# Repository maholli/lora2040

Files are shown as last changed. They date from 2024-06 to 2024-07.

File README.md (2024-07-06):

# lora2040

Just playing with RP2040 w/ mram + SX1262 radio.

Will eventually reduce the size and add castellations for "mezzanine" style surface mounting.



# Example Software - Meshtastic RX
1. Open serial terminal ([can use chrome or edge with this link](https://googlechromelabs.github.io/serial-terminal/) if you don't already have a preferred serial terminal method)
   
2. Ctrl+e for paste-mode
3. Paste the following:
   ```python
   import time
   from machine import Pin, SPI
   # Uses the official micropython-lib lora sx1262 lib
   # https://github.com/micropython/micropython-lib/tree/master/micropython/lora
   from lora import SX1262
   
   # meshtastic default "LongFast" on default frequency slot 20
   lora_cfg = {
       "freq_khz": 906_875,
       "sf": 11,
       "bw": "250",  # kHz
       "coding_rate": 5,
       "preamble_len": 16,
       "output_power": 0,  # dBm
       # "syncword":0x2B, # SETTING SYNCWORD MUST BE DONE MANUALLY. SEE BELOW
       "rx_boost":True,
   }
      
   print("Initializing...")
   
   modem = SX1262(
       spi=SPI(0, baudrate=8_000_000, polarity=0, phase=0,
               sck=Pin(18), miso=Pin(16), mosi=Pin(19)),
       cs=Pin(17),
       reset=Pin(20),
       busy=Pin(21),
       dio1=Pin(25),
       dio2_rf_sw=True,
       dio3_tcxo_millivolts=2800,
       lora_cfg=lora_cfg,
   )
   
   # set custom meshtastic syncword
   modem._cmd(">BHH", 0x0D, 0x740, 0x24b4) # 0x2B == 0x24b4
   
   print("Listening...")
   
   print("[Packet payload, Timestamp (ms), SNR (dB*4), RSSI (dBm), Valid CRC]")
   while True:
       modem.recv()
   ```
4. Ctrl+d to run
5. Any packets received will be printed (note meshtastic payloads will still be encrypted):
   

-----

Reminders to myself:
- [x] Initial bring-up with Everspin MRAM
  - [ ] Avalanche MRAM
- [x] Full speed SX1262 interface
- [ ] Measure TX output power
- [ ] Measure RX sensitivity
- [ ] Maybe add an amp at some point?

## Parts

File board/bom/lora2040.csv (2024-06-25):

Reference | Value | Footprint | Qty | Part Number | Manufacturer | Description
C1 | 47nF | custom-footprints:sx126x_C_0201 | 1 |  |  | Multilayer ceramic capacitors X5R ±10%, 16V
C2 | 47pF | custom-footprints:sx126x_C_0201 | 1 |  |  | Multilayer ceramic capacitors COG ±5%, 50V
C3,C4 | 15pF | custom-footprints:sx126x_C_0201 | 2
C5,C6,C10,C11,C12,C13,C18,C21,C23 | 0.1uF | custom-footprints:sx126x_C_0201 | 9 |  |  | -- mixed values --
C7,C9,C24,C26 | 1uF | Capacitor_SMD:C_0402_1005Metric | 4
C8 | 39pF | custom-footprints:sx126x_C_0201 | 1 |  |  | Multilayer ceramic capacitors COG ±5%, 50V
C14,C15 | 1nF | custom-footprints:sx126x_C_0201 | 2 |  |  | Unpolarized capacitor, small symbol
C16 | 1uF | custom-footprints:sx126x_C_0402 | 1 |  |  | Unpolarized capacitor, small symbol
C17 | 470nF | custom-footprints:sx126x_C_0402 | 1 |  |  | Unpolarized capacitor, small symbol
C19,C20 | 0.1uF | Capacitor_SMD:C_0402_1005Metric | 2
C22 | 10pF | custom-footprints:sx126x_C_0201 | 1 |  |  | Unpolarized capacitor, small symbol
C25 | 10nF | Capacitor_SMD:C_0402_1005Metric | 1
C27 | 10uF | Capacitor_SMD:C_0402_1005Metric | 1
D1 | LED | LED_SMD:LED_0402_1005Metric | 1 |  |  | Light emitting diode
FB1 | BLM15PG100SN1D | custom-footprints:sx126x_L_0402 | 1 | BLM15PG100SN1D | Murata Electronics | Ferrite bead, small symbol
J1 | u.FL | Connector_Coaxial:U.FL_Hirose_U.FL-R-SMT-1_Vertical | 1 |  |  | coaxial connector (BNC, SMA, SMB, SMC, Cinch/RCA, LEMO, ...)
J2 | USB_B_Micro | Connector_USB:USB_Micro-B_Molex-105017-0001 | 1 |  |  | USB Micro Type B connector
J5 | Conn_01x02 | Connector_PinHeader_1.00mm:PinHeader_1x02_P1.00mm_Vertical | 1 |  |  | Generic connector, single row, 01x02, script generated (kicad-library-utils/schlib/autogen/connector/)
J6 | Conn_02x06_Odd_Even | Connector_PinHeader_1.00mm:PinHeader_2x06_P1.00mm_Vertical | 1 |  |  | Generic connector, double row, 02x06, odd/even pin numbering scheme (row 1 odd numbers, row 2 even numbers), script generated (kicad-library-utils/schlib/autogen/connector/)
J8 | Conn_01x04 | Connector_PinHeader_1.00mm:PinHeader_1x04_P1.00mm_Vertical | 1 |  |  | Generic connector, single row, 01x04, script generated (kicad-library-utils/schlib/autogen/connector/)
L1 | 47nH | custom-footprints:sx126x_L_0402 | 1 | LQW15AN47NJ00D | Murata Electronics | FIXED IND 47NH 210MA 1.08OHM SMD
L7 | 15uH | custom-footprints:sx126x_L_0805 | 1 | MLZ2012M150WT000 | TDK Corporation | FIXED IND 15UH 250MA 950MOHM SMD
R1,R9 | 10K | custom-footprints:sx126x_R_0201 | 2
R2 | 1K | Resistor_SMD:R_0402_1005Metric | 1
R3,R4 | 100 | custom-footprints:sx126x_R_0201 | 2
R6,R7 | 27 | custom-footprints:sx126x_R_0201 | 2
R8,R11 | 1K | custom-footprints:sx126x_R_0201 | 2
R10 | 220 | custom-footprints:sx126x_R_0201 | 1
U1 | SX1262IMLTRT | custom-footprints:VQFN24_4X4MM_SX126x | 1 | SX1262IMLTRT | Semtech Corporation | 150 MHz to 960 MHz Low Power Long Range Transceiver, 22dBm output power, spreading factor from 5 to 12, LoRA, QFN-24
U2 | BGS12WN6E6327 | Package_LGA:Infineon_PG-TSNP-6-10_0.7x1.1mm_0.7x1.1mm_P0.4mm | 1 | BGS12WN6E6327 | Infineon Technologies | SPDT DC-9GHz switch, 45dB isolation at 960MHz, PG-TSNP-6-10
U3 | 0900FM15K0039001E | custom-footprints:0900FM15K0039 | 1 | 0900FM15K0039001E | Johanson Technology Inc. | 868MHz/915MHz Sub-GHz Impedance Matched Filter integrated passive for Semtech SX1261, SX1262, LLCC68
U4 | MR20H40 or AS3004204 | custom-footprints:SON127P600X500X90-9N | 1 | AS3004204-0054X0PWAY | Avalanche Technology | 4Mb MRAM memory with SPI interface, DFN-8
U5 | RP2040 | Package_DFN_QFN:QFN-56-1EP_7x7mm_P0.4mm_EP3.2x3.2mm | 1 | SC0914 | Raspberry Pi | IC MCU 32BIT EXT MEM 56QFN
U6 | RTX-2016BD32-S-32.000-TR | custom-footprints:TXCO_2.0x1.6 | 1 | RTX-2016BD32-S-32.000-TR | Raltron Electronics | Raltron Electronics XTAL OSC TCXO 32MHZ 2.8V CLP SNW
U7 | TPS73633DBV or MIC5219-3.3YM5-TR? | Package_TO_SOT_SMD:SOT-23-5 | 1 | MIC5219-3.3YM5-TR | Microchip Technology | Cap free NMOS 400mA Low Drop 3.3V Regulator, SOT-23-5
Y2 | ABM8-272-T3 | Crystal:Crystal_SMD_3225-4Pin_3.2x2.5mm | 1 | ABM8-272-T3 | Abracon LLC | CRYSTAL 12.0000MHZ 10PF SMD GND ON 2 AND 4

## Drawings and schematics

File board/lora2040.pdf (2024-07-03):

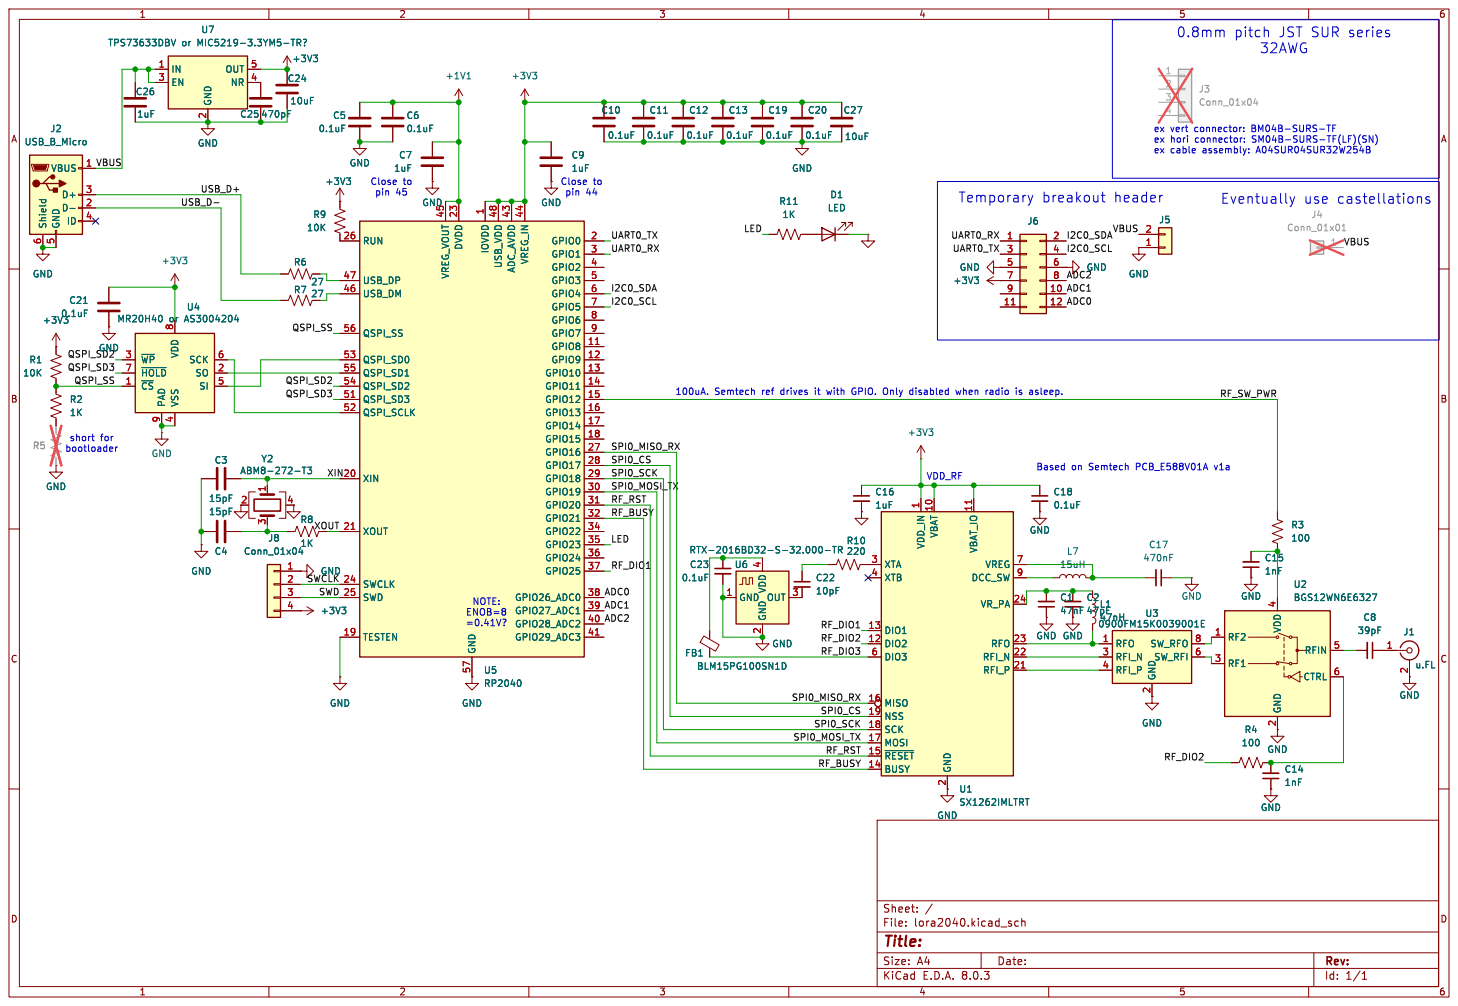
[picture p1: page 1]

2 EN 3 NR 4 OUT 5 U7 TPS73633DBV or MIC5219-3.3YM5-TR? C13

2 EN 3 NR 4 OUT 5 U4 MR20H40 or AS3004204 ~{CS} 1 SO 2 ~{WP} 3 VSS

1 GPIO8 11 GPIO9 12 GPIO10 13 GPIO11 14 GPIO12 15 GPIO13 16 GPIO14 17 GPIO15 18 TESTEN 19 GPIO0 2 XIN 20 XOUT 21 DVDD 23 SWCLK 24 SWD 25 RUN 26 GPIO16 27 GPIO17 28 GPIO18 29 GPIO1 3 GPIO19 30 GPIO20 31 GPIO21 32 GPIO22 34 GPIO23 35 GPIO24 36 GPIO25 37 GPIO26_ADC0 38 GPIO27_ADC1 39 GPIO2 4 GPIO28_ADC2 40 GPIO29_ADC3 41 ADC_AVDD 43 VREG_IN 44 VREG_VOUT 45 USB_DM 46 USB_DP 47 USB_VDD 48 GPIO3 5 QSPI_SD3 51 QSPI_SCLK 52 QSPI_SD0 53 QSPI_SD2 54 QSPI_SD1 55 QSPI_SS 56 GND 57 GPIO4 6 GPIO5 7 GPIO6 8 GPIO7 9 U5 RP2040

1 GPIO8 11 GPIO9 12 GPIO10 13 GPIO11 14 GPIO12 15 GPIO13 16 GPIO14 17 GPIO15 18 TESTEN 19 GPIO0 2 XIN 20 XOUT 21 DVDD 23 SWCLK 24 SWD 25 RUN 26 GPIO16 27 GPIO17 28 GPIO18 29 GPIO1 3 GPIO19 30 GPIO20 31 GPIO21 32 GPIO22 34 GPIO23 35 GPIO24 36 GPIO25 37 GPIO26_ADC0 38 GPIO27_ADC1 39 GPIO2 4 GPIO28_ADC2 40 GPIO29_ADC3 41 ADC_AVDD 43 VREG_IN 44 VREG_VOUT 45 USB_DM 46 USB_DP 47 USB_VDD 48 GPIO3 5 QSPI_SD3 51 QSPI_SCLK 52 QSPI_SD0 53 QSPI_SD2 54 QSPI_SD1 55 QSPI_SS 56 GND 57 GPIO4 6 GPIO5 7 GPIO6 8 GPIO7 9 GND

2 OUT VDD 3 U6 4 RTX-2016BD32-S-32.000-TR IOVDD

4 SI 5 SCK 6 ~{HOLD} 7 VDD

1 VBAT 10 VBAT_IO 11 DIO2 12 DIO1 13 BUSY 14 ~{RESET} 15 MISO 16 MOSI 17 SCK 18 NSS 19 GND

2 RFI_P 21 RFI_N 22 RFO 23 VR_PA 24 XTA 3 XTB 4 DIO3 6 VREG 7 DCC_SW 9 U1SX1262IMLTRT R4

2 RFI_P 21 RFI_N 22 RFO 23 VR_PA 24 XTA 3 XTB 4 DIO3 6 VREG 7 DCC_SW 9 GND

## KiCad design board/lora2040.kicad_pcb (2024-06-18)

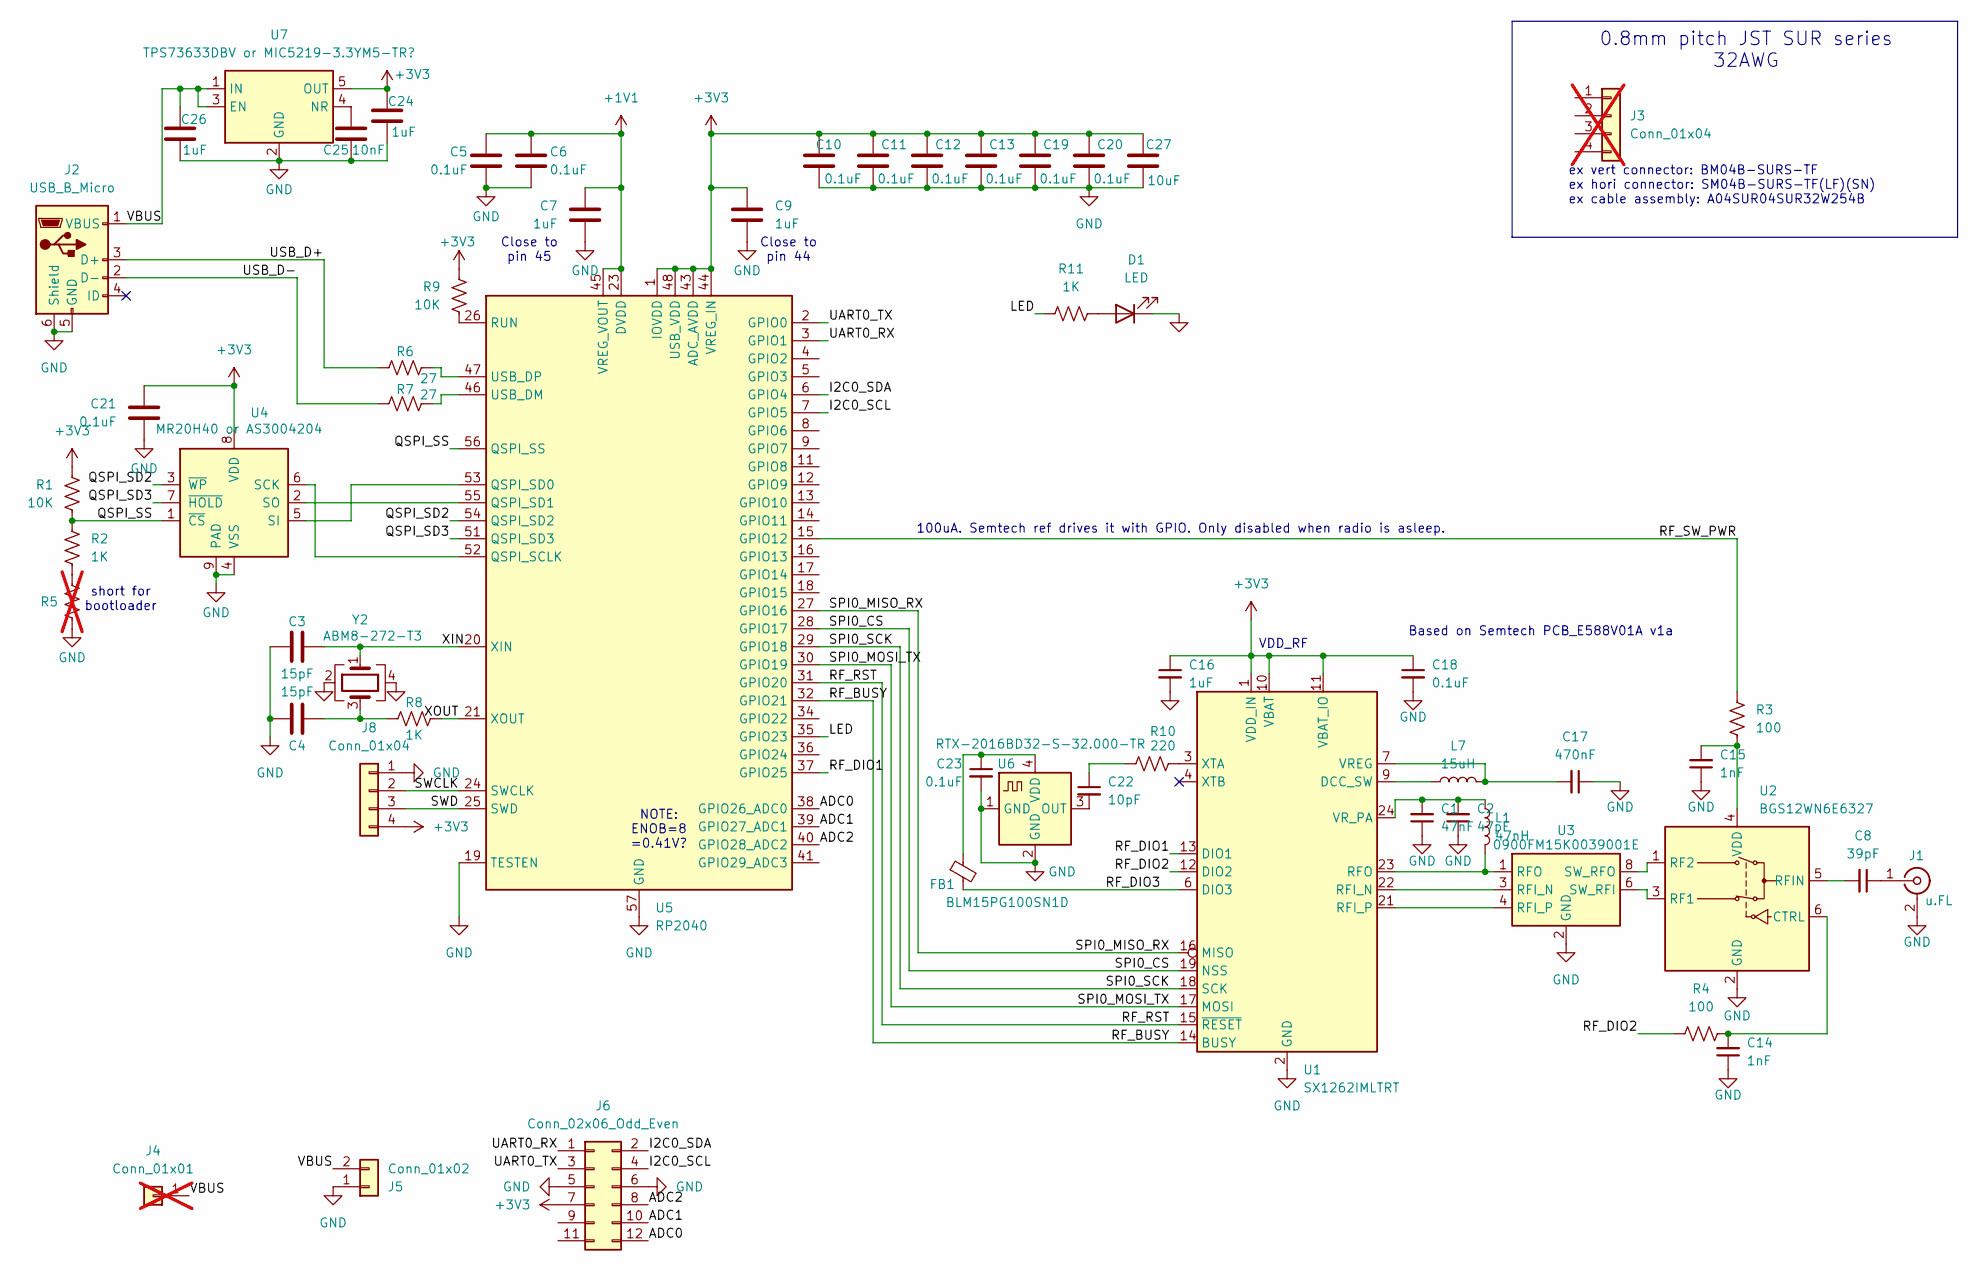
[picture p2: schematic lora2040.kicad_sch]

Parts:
C1: 47nF; sx126x_C_0201
C2: 47pF; sx126x_C_0201
C3, C4: 15pF; sx126x_C_0201
C5, C6, C10, C11, C12, C13, C18, C21, C23: 0.1uF; sx126x_C_0201
C7, C9, C24, C26: 1uF; C_0402_1005Metric
C8: 39pF; sx126x_C_0201
C14, C15: 1nF; sx126x_C_0201
C16: 1uF; sx126x_C_0402
C17: 470nF; sx126x_C_0402
C19, C20: 0.1uF; C_0402_1005Metric
C22: 10pF; sx126x_C_0201
C25: 10nF; C_0402_1005Metric
C27: 10uF; C_0402_1005Metric
D1: LED; LED_0402_1005Metric
FB1: BLM15PG100SN1D; sx126x_L_0402; Part Number BLM15PG100SN1D
J1: u.FL; U.FL_Hirose_U.FL-R-SMT-1_Vertical
J2: USB_B_Micro; USB_Micro-B_Molex-105017-0001
J3: Conn_01x04; JST_SUR_BM04B-SURS-TF_1x04-1MP_P0.80mm_Vertical; not fitted
J4: Conn_01x01; castellated_07mm; not fitted
J5: Conn_01x02; PinHeader_1x02_P1.00mm_Vertical
J6: Conn_02x06_Odd_Even; PinHeader_2x06_P1.00mm_Vertical
J8: Conn_01x04; PinHeader_1x04_P1.00mm_Vertical
L1: 47nH; sx126x_L_0402; Part Number LQW15AN47NJ00D
L7: 15uH; sx126x_L_0805; Part Number MLZ2012M150WT000
R1, R9: 10K; sx126x_R_0201
R2: 1K; R_0402_1005Metric
R3, R4: 100; sx126x_R_0201
R5: 0; R_0402_1005Metric; not fitted
R6, R7: 27; sx126x_R_0201
R8, R11: 1K; sx126x_R_0201
R10: 220; sx126x_R_0201
U1: SX1262IMLTRT; VQFN24_4X4MM_SX126x; Part Number SX1262IMLTRT
U2: BGS12WN6E6327; Infineon_PG-TSNP-6-10_0.7x1.1mm_0.7x1.1mm_P0.4mm; Part Number BGS12WN6E6327
U3: 0900FM15K0039001E; 0900FM15K0039; Part Number 0900FM15K0039001E
U4: MR20H40 or AS3004204; SON127P600X500X90-9N; Part Number AS3004204-0054X0PWAY
U5: RP2040; QFN-56-1EP_7x7mm_P0.4mm_EP3.2x3.2mm; Part Number SC0914
U6: RTX-2016BD32-S-32.000-TR; TXCO_2.0x1.6; Part Number RTX-2016BD32-S-32.000-TR
U7: TPS73633DBV or MIC5219-3.3YM5-TR?; SOT-23-5; Part Number MIC5219-3.3YM5-TR
Y2: ABM8-272-T3; Crystal_SMD_3225-4Pin_3.2x2.5mm; Part Number ABM8-272-T3

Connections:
+1V1: C5.2, C6.2, C7.2, U5.23 (DVDD), U5.45 (VREG_VOUT), U5.50 (DVDD)
+3V3: C9.2, C10.2, C11.2, C12.2, C13.2, C16.1, C18.1, C19.2, C20.2, C21.2, C24.2, C27.2, J6.7, J8.4, R1.2, R9.2, U1.1 (VDD_IN), U1.10 (VBAT), U1.11 (VBAT_IO), U4.8 (VDD), U5.1 (IOVDD), U5.10 (IOVDD), U5.22 (IOVDD), U5.33 (IOVDD), U5.42 (IOVDD), U5.43 (ADC_AVDD), U5.44 (VREG_IN), U5.48 (USB_VDD), U5.49 (IOVDD), U7.5 (OUT)
/ADC0: J6.12, U5.38 (GPIO26_ADC0)
/ADC1: J6.10, U5.39 (GPIO27_ADC1)
/ADC2: J6.8, U5.40 (GPIO28_ADC2)
/I2C0_SCL: J6.4, U5.7 (GPIO5)
/I2C0_SDA: J6.2, U5.6 (GPIO4)
/LED: R11.1, U5.35 (GPIO23)
/QSPI_SD2: U4.3 (~WP), U5.54 (QSPI_SD2)
/QSPI_SD3: U4.7 (~HOLD), U5.51 (QSPI_SD3)
/QSPI_SS: R1.1, R2.2, U4.1 (~CS), U5.56 (QSPI_SS)
/RF_BUSY: U1.14 (BUSY), U5.32 (GPIO21)
/RF_DIO1: U1.13 (DIO1), U5.37 (GPIO25)
/RF_DIO2: R4.1, U1.12 (DIO2)
/RF_DIO3: FB1.2, U1.6 (DIO3)
/RF_RST: U1.15 (~RESET), U5.31 (GPIO20)
/RF_SW_PWR: R3.2, U5.15 (GPIO12)
/SPI0_CS: U1.19 (NSS), U5.28 (GPIO17)
/SPI0_MISO_RX: U1.16 (MISO), U5.27 (GPIO16)
/SPI0_MOSI_TX: U1.17 (MOSI), U5.30 (GPIO19)
/SPI0_SCK: U1.18 (SCK), U5.29 (GPIO18)
/SWCLK: J8.2, U5.24 (SWCLK)
/SWD: J8.3, U5.25 (SWD)
/UART0_RX: J6.1, U5.3 (GPIO1)
/UART0_TX: J6.3, U5.2 (GPIO0)
/USB_D+: J2.3 (D+), R6.1
/USB_D-: J2.2 (D-), R7.1
/VBUS: C26.2, J2.1 (VBUS), J4.1, J5.2, U7.1 (IN), U7.3 (EN)
/XIN: C3.2, U5.20 (XIN), Y2.1
/XOUT: R8.2, U5.21 (XOUT)
GND: C1.1, C2.1, C3.1, C4.1, C5.1, C6.1, C7.1, C9.1, C10.1, C11.1, C12.1, C13.1, C14.1, C15.1, C16.2, C17.1, C18.2, C19.1, C20.1, C21.1, C23.2, C24.1, C25.1, C26.1, C27.1, D1.1 (K), J1.2 (Ext), J2.5 (GND), J2.6 (Shield), J5.1, J6.5, J6.6, J8.1, R5.1, U1.2 (GND), U1.5 (GND), U1.8 (GND), U1.20 (GND), U1.25 (GND), U2.2 (GND), U3.2 (GND), U3.5 (GND), U3.7 (GND), U3.9 (GND), U3.10 (GND), U4.4 (VSS), U4.9 (PAD), U5.19 (TESTEN), U5.57 (GND), U6.1 (GND), U6.2 (GND), U7.2 (GND), Y2.2, Y2.4
unnamed: C4.2, R8.1, Y2.3
unnamed: C22.1, R10.1
unnamed: D1.2 (A), R11.2
unnamed: C8.1, J1.1 (In)
unnamed: R2.1, R5.2
unnamed: L7.1, U1.9 (DCC_SW)
unnamed: U1.22 (RFI_N), U3.3 (RFI_N)
unnamed: U1.21 (RFI_P), U3.4 (RFI_P)
unnamed: L1.2, U1.23 (RFO), U3.1 (RFO)
unnamed: C17.2, L7.2, U1.7 (VREG)
unnamed: C1.2, C2.2, L1.1, U1.24 (VR_PA)
unnamed: R10.2, U1.3 (XTA)
unnamed: C14.2, R4.2, U2.6 (CTRL)
unnamed: U2.3 (RF1), U3.6 (SW_RFI)
unnamed: U2.1 (RF2), U3.8 (SW_RFO)
unnamed: C8.2, U2.5 (RFIN)
unnamed: C15.2, R3.1, U2.4 (VDD)
unnamed: U4.6 (SCK), U5.52 (QSPI_SCLK)
unnamed: U4.5 (SI), U5.53 (QSPI_SD0)
unnamed: U4.2 (SO), U5.55 (QSPI_SD1)
unnamed: R9.1, U5.26 (RUN)
unnamed: R7.2, U5.46 (USB_DM)
unnamed: R6.2, U5.47 (USB_DP)
unnamed: C22.2, U6.3 (OUT)
unnamed: C23.1, FB1.1, U6.4 (VDD)
unnamed: C25.2, U7.4 (NR)

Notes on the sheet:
0.8mm pitch JST SUR series 32AWG
ex vert connector: BM04B-SURS-TF ex hori connector: SM04B-SURS-TF(LF)(SN) ex cable assembly: A04SUR04SUR32W254B
NOTE: ENOB=8 =0.41V?
100uA. Semtech ref drives it with GPIO. Only disabled when radio is asleep.
Close to pin 45
VDD_RF
Close to pin 44
short for bootloader
Based on Semtech PCB_E588V01A v1a

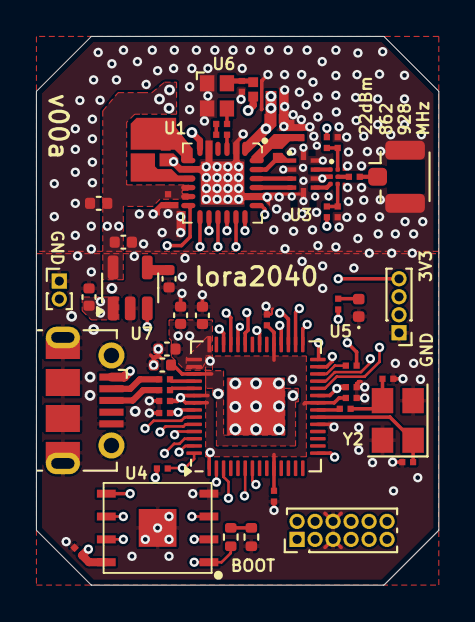
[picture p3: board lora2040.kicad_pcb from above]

Board: 4 copper layers, 22.4 x 30.5 mm, 55 parts (0 on the bottom side), 57 nets.

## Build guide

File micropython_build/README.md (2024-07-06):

Very quick and dirty micropython build for 512KB MRAM. Works, but nothing has been optimized, relevant libraries not baked into the firmware, etc...

1. place `LORA2040` directory in https://github.com/micropython/micropython/tree/master/ports/rp2/boards
2. `make BOARD=LORA2040`

Note that I've only allocated 128KB for user code space.

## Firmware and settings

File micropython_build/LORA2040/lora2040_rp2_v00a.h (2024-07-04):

// Board definition for the PyCubed Mainboard RP2040 v00

#ifndef _BOARDS_LORA2040_RP2_V00A_H
#define _BOARDS_LORA2040_RP2_V00A_H

// For board detection
#define LORA2040_RP2_V00A

// On some samples, the xosc can take longer to stabilize than is usual
#ifndef PICO_XOSC_STARTUP_DELAY_MULTIPLIER
#define PICO_XOSC_STARTUP_DELAY_MULTIPLIER 64
#endif

// --- UART ---
#ifndef PICO_DEFAULT_UART
#define PICO_DEFAULT_UART 0
#endif
#ifndef PICO_DEFAULT_UART_TX_PIN
#define PICO_DEFAULT_UART_TX_PIN 0
#endif
#ifndef PICO_DEFAULT_UART_RX_PIN
#define PICO_DEFAULT_UART_RX_PIN 1
#endif

// --- LED ---
#ifndef PICO_DEFAULT_LED_PIN
#define PICO_DEFAULT_LED_PIN 23
#endif

// --- I2C ---
#ifndef PICO_DEFAULT_I2C
#define PICO_DEFAULT_I2C 0
#endif
#ifndef PICO_DEFAULT_I2C_SDA_PIN
#define PICO_DEFAULT_I2C_SDA_PIN 4
#endif
#ifndef PICO_DEFAULT_I2C_SCL_PIN
#define PICO_DEFAULT_I2C_SCL_PIN 5
#endif

// --- SPI ---
#ifndef PICO_DEFAULT_SPI
#define PICO_DEFAULT_SPI 0
#endif
#ifndef PICO_DEFAULT_SPI_SCK_PIN
#define PICO_DEFAULT_SPI_SCK_PIN 18
#endif
#ifndef PICO_DEFAULT_SPI_TX_PIN
#define PICO_DEFAULT_SPI_TX_PIN 19
#endif
#ifndef PICO_DEFAULT_SPI_RX_PIN
#define PICO_DEFAULT_SPI_RX_PIN 16
#endif
#ifndef PICO_DEFAULT_SPI_CSN_PIN
#define PICO_DEFAULT_SPI_CSN_PIN 17
#endif

// --- FLASH ---

#define PICO_BOOT_STAGE2_CHOOSE_GENERIC_03H 1
#ifndef PICO_FLASH_NO_ERASE_CMD
#define PICO_FLASH_NO_ERASE_CMD 1
#endif

#ifndef PICO_FLASH_SPI_CLKDIV
#define PICO_FLASH_SPI_CLKDIV 6
#endif

#ifndef PICO_FLASH_SIZE_BYTES
#define PICO_FLASH_SIZE_BYTES (500 * 1024)
#endif

// Drive high to force power supply into PWM mode (lower ripple on 3V3 at light loads)
// #define PICO_SMPS_MODE_PIN 23

#ifndef PICO_RP2040_B0_SUPPORTED
#define PICO_RP2040_B0_SUPPORTED 1
#endif

// The GPIO Pin used to read VBUS to determine if the device is battery powered.
// #ifndef PICO_VBUS_PIN
// #define PICO_VBUS_PIN 24
// #endif

// The GPIO Pin used to monitor VSYS. Typically you would use this with ADC.
// There is an example in adc/read_vsys in pico-examples.
// #ifndef PICO_VSYS_PIN
// #define PICO_VSYS_PIN 29
// #endif

#endif

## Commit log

2024-06-11 roughing in parts as I think of it
    [lora2040.kicad_pcb, lora2040.kicad_sch]
2024-06-16 added in sx1262 ref design
    [lora2040.kicad_pcb, lora2040.kicad_sch]
2024-06-16 about to switch to TXCO
    [lora2040.kicad_pcb, lora2040.kicad_sch]
2024-06-16 changed to TXCO
    [lora2040.kicad_pcb, lora2040.kicad_sch]
2024-06-16 seeing what castelations look like
    [lora2040.kicad_pcb]
2024-06-17 routing tests
    [lora2040.kicad_pcb, lora2040.kicad_sch]
2024-06-18 BOM clean up and routing
    [lora2040.kicad_pcb, lora2040.kicad_sch]
2024-06-18 v00a manufacturing files
    [lora2040-B_Cu.gbl, lora2040-B_Mask.gbs, lora2040-B_Paste.gbp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]
2024-06-25 schematic cleanup and BOM
    [lora2040.csv, lora2040.kicad_sch]
